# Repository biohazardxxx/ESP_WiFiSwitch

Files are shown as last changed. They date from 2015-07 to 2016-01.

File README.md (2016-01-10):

# ESP WiFiSwitch
## General info
This sketch is for a WiFi enabled wall light switch with focus to reliable pushbutton switch.
In the beginning or (if no WiFi connection) it is running a web server to configure WiFI (and MQTT if desired). 
Each second start up switch will load into OTA mode. By this you can upload a new firmware (compiled *.bin file) via web browser. The OTA mode will end after set timeout and restart into desired mode.
The operation mode can be web server or MQTT to change the state of the light.
The push button have to switch to ground.
## Button functions
* Normal press less than 1 sec but more than 50ms-> Switch light.
* Restart press: 3 sec -> Restart the module.
* Reset press: 20 sec -> Clear the settings in EEPROM

## URL adresses
* While a WiFi config is not set or can't connect:
   * http://server_ip
   *-> Gives a WiFi config page 
  
* While a WiFi config is set and in Web control mode (iotMode==0):
 * http://server_ip/gpio
  * Will display the GIPIO state and a switch form for it
  
 * http://server_ip/gpio?state=0
  * Will change the GPIO directly and display the above aswell
  
 * http://server_ip/cleareeprom 
  * Will reset the WiFi setting and rest to configure mode as AP
  * 
* While in OTA mode each second start:
   * http://server_ip
   *-> Gives a WiFi config page 
  
<b>server_ip</b> is the IP address of the ESP8266 module, will be printed to Serial when the module is connected.

## Hardware setup
Your WiFi switch should be connected like this

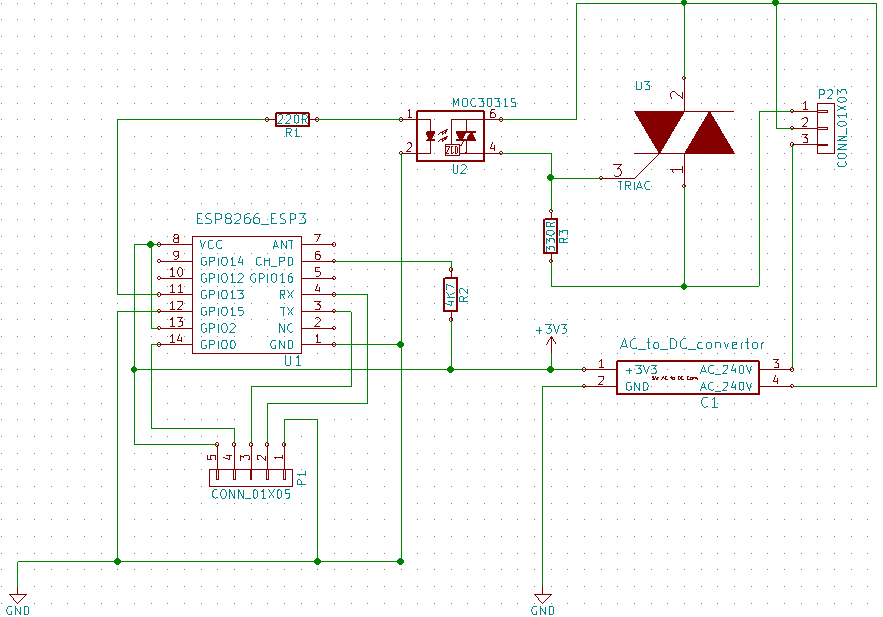
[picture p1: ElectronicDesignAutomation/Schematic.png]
Schematic


You can reorder the working PCB here: https://oshpark.com/shared_projects/xoEZ3PnV or get it from any where else from the KiCad design files "ElectronicDesignAutomation" folder.

## Parts list
* ESP8266-03 module
* AC to DC Power Module Supply Isolation Input: AC90-240V Output: 3.3V 500mA like this * http://www.ebay.com/itm/271636529720?_trksid=p2060353.m2749.l2649&ssPageName=STRK%3AMEBIDX%3AIT
* Resistor 220 Ohm SMD 1206        1x
* Resistor 330 Ohm SMD 1206        1x
* Resistor 4k7 SMD 1206   1x
* Optocuppler MOC3040  SMD      1x
* Tryac BT136D     1x

## Usage
<b>For default usage you can use the pre build firmware and flash it with NodeMcu flasher.</b>

After fresh flash please restart the module manualy (power Off & On) otherwise software restart will not work and sometimes WiFi connect does not work.

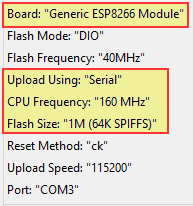
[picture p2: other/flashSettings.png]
fLashSetting
When manually compile and flash with Arduino IDE please make sure to have this flash settings: 

Open the modules page after entering config mode (Press button >20secs if you want to enter again) via http://server_ip there you can setup to be MQTT controled or Web controled.

## Credits
For several snippets used the credit goes to:
 - https://github.com/esp8266
 - https://github.com/chriscook8/esp-arduino-apboot
 - https://github.com/knolleary/pubsubclient
 - https://github.com/vicatcu/pubsubclient <- Currently this needs to be used instead of the origin
 - https://gist.github.com/igrr/7f7e7973366fc01d6393
 - http://www.esp8266.com/viewforum.php?f=25
 - http://www.esp8266.com/viewtopic.php?f=29&t=2745
 - And the whole Arduino and ESP8266 comunity

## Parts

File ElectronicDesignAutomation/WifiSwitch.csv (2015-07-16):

Reference | Value | Footprint | Datasheet
U1 | ESP8266_ESP3 | WifiSwitch:ESP8266-ESP-03
U2 | MOC3031S | WifiSwitch:DIP-6_SMD
C1 | AC_to_DC_convertor | WifiSwitch:AC_DC_Conv
R2 | 10K | Resistors_SMD:R_1206_HandSoldering
R3 | 330R | Resistors_SMD:R_1206_HandSoldering
P1 | CONN_01X05 | Pin_Headers:Pin_Header_Angled_1x05
P2 | CONN_01X03 | WifiSwitch:WirePad_3x-5mmDrill
U3 | TRIAC | Transistors_TO-220:TO-220_Neutral123_Horizontal_LargePads
R1 | 220R | Resistors_SMD:R_1206_HandSoldering

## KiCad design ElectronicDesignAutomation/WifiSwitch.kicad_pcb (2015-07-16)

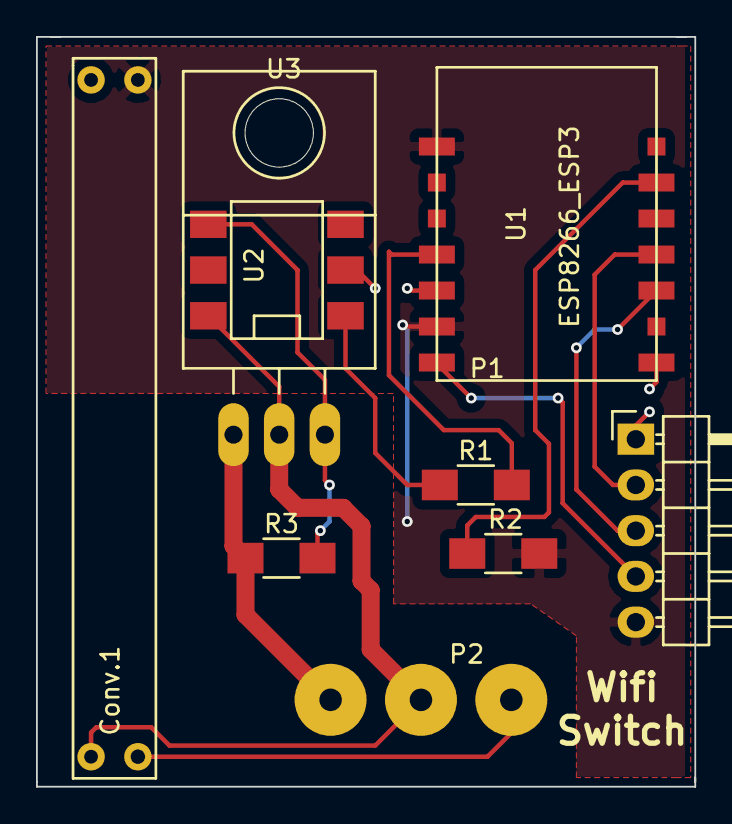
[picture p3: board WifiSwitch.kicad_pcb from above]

Board: 2 copper layers, 36.6 x 41.7 mm, 9 parts (0 on the bottom side), 12 nets.

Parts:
Conv.1: AC to DC convertor 3V3; AC_DC_Conv
P1: CONN_01X05; Pin_Header_Angled_1x05
P2: CONN_01X03; WirePad_3x-5mmDrill
R1: 220R; R_1206_HandSoldering
R2: 4K7; R_1206_HandSoldering
R3: 330R; R_1206_HandSoldering
U1: ESP8266_ESP3; ESP8266-ESP-03
U2: MOC3031S; DIP-6_SMD
U3: TRIAC; TO-220_Neutral123_Horizontal_LargePads

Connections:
+3V3: Conv.1.1, P1.5, R2.2, U1.8, U1.13
GND: Conv.1.2, P1.1, U1.1, U1.12, U2.2
unnamed: Conv.1.3, P2.3
unnamed: Conv.1.4, P2.2, U2.6, U3.2
unnamed: P1.2, U1.4
unnamed: P1.3, U1.3
unnamed: P1.4, U1.14
unnamed: P2.1, R3.2, U3.1
unnamed: R1.1, U2.1
unnamed: R1.2, U1.11
unnamed: R2.1, U1.6
unnamed: R3.1, U2.4, U3.3

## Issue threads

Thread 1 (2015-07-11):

Disconnection after sending or receiving messages...

Rigyu, 2015-07-11:
Have been testing your awesome project but have found some bug...

The client connects successfully but after some message it drops the connection.

This is a sample output, have tested with 3 different servers. ¿Any help?

 .....
WiFi connected
Connecting to MQTT server test.mosquitto.org as WiFiSwitch-18:fe:34:9f:9b:30
Connected to MQTT broker
Subsribed to topic.
MQTT message arrived:  topic: test message: 1
Light is 0
Switching light to high
MQTT message arrived:  topic: test message: 1
Light is 1
Switching light to high
Connecting to MQTT server test.mosquitto.org as WiFiSwitch-18:fe:34:9f:9b:30-18:fe:34:9f:9b:30
MQTT connect failed!
Connecting to MQTT server test.mosquitto.org as WiFiSwitch-18:fe:34:9f:9b:30-18:fe:34:9f:9b:30-18:fe:34:9f:9b:30
MQTT connect failed!
Connecting to MQTT server test.mosquitto.org as WiFiSwitch-18:fe:34:9f:9b:30-18:fe:34:9f:9b:30-18:fe:34:9f:9b:30-18:fe:34:9f:9b:30
MQTT connect failed!
Connecting to MQTT server test.mosquitto.org as WiFiSwitch-18:fe:34:9f:9b:30-18:fe:34:9f:9b:30-18:fe:34:9f:9b:30-18:fe:34:9f:9b:30-18:fe:34:9f:9b:30

Also tested in a private sever with mosquitto 1.4.2.

biohazardxxx, 2015-07-11:
Hi,
I'm using mosquito 1.3.1 on debian. Can you try with that Version? I'm not
sure yet what versions are supported by pubsubclient.
Br
Bio
Am 11.07.2015 3:57 vorm. schrieb "Rigyu" <notifications@github.com>:

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

Rigyu, 2015-07-11:
Used mosquito 1.3.1 debian install... same result. It connects 5 ~ 10 seconds, then it goes forever in "Connecting to [...]..."

Rigyu, 2015-07-11:
SOLVED. Was my router fault. I have a TP-Link "TL-WR741ND" with bgn mixed mode selected, changed to use only b and now the connection it's ok. Thank you for your time.

biohazardxxx, 2015-07-12:
Glad you solved it!

Closed 2015-07-12.

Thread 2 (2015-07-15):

mqtt works perfectly but http code hangs after a few minutes

rajbadri, 2015-07-15:
hi
i tested a relay connected to the esp8266 in mqtt mode and the setup ran perfectly for days but when i put the esp in http mode it stops responding after a few minutes.

biohazardxxx, 2015-07-17:
Hi,
I could not recreate your described issue.
(18:58:52.25) Startup
(18:58:52.40) Connecting to WiFi ABCD
(18:58:52.48) Wifi test...
(18:58:53.49) .......
(18:58:56.50) WiFi connected
(18:58:56.50) mDNS responder started
(18:58:56.50) 192.168.0.144
(18:58:56.50) Web server started
(18:59:30.27) Light switched via web request to  1
(18:59:33.69) Light switched via web request to  0
(19:03:07.47) Sending 200
(19:07:04.14) Light switched via web request to  1
(19:07:08.30) Light switched via web request to  0

I've just added more logging to the sketch for this issue. Do you get anything on serial? Can you check your DHCP leas time?

biohazardxxx, 2015-08-04:
I assume you lost the interest or could fix your problem meanwhile so I'm closing this issue.

Closed 2015-08-04.

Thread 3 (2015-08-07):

getting compile error message

rajbadri, 2015-08-07:
hi
i am getting this error message when i try to compile your sketch

Arduino: 1.6.5 (Mac OS X), Board: "Generic ESP8266 Module, Serial, 80 MHz, 40MHz, DIO, 115200, 4M (3M SPIFFS)"

In file included from sketch_aug07b.ino:31:0:
/Users/rajbadri/Documents/Arduino/libraries/PubSubClient/PubSubClient.h:80:46: error: section attribute not allowed for '<anonymous>'
    boolean publish_P(char *, uint8_t PROGMEM *, unsigned int, boolean);
                                              ^
Error compiling.

biohazardxxx, 2015-08-10:
Hi,

have you made sure to use the right pubSubClient version? https://github.com/vicatcu/pubsubclient
Because I have at line 80 in PubSubClient.h:   boolean subscribe(char *);

rajbadri, 2015-08-11:
i downloaded the pubsubclient from your link but getting the same error.
i deleted all references of PROGMEM from the library and now the sketch is compiling and running ok.
but is it ok to delete PROGMEM will it affect the working of esp8266

Thanks

rajbadri, 2015-08-11:
another question : can i give the esp a fixed ip address

Thanks again

biohazardxxx, 2015-08-11:
The simple way is to assign it within your DHCP settings at your router
config. But within the sketch you can achieve it with:
WiFi.begin(<ssid>,<pass>);
IPAddress ip(192,168,1,124);
IPAddress gateway(192,168,1,1);
IPAddress subnet(255,255,255,0);
WiFi.config(ip, gateway, subnet);

but that would be static. Adding this as option to the webconfig would need
some more coding. I'll add it to the roadmap.

2015-08-11 5:58 GMT+02:00 Raj Badri <notifications@github.com>:

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

rajbadri, 2015-08-11:
Thanks

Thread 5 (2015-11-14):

Fritzing picture

rajbadri, 2015-11-14:
hi
i have ordered pcb of your design from osh-park. but being a novice don't get the layout of button correctly. if you can post a fritzing picture of your design it will be of great help. Also can i replace the Triac BT136D with BT136

thanks for your help

Raj

rajbadri, 2015-11-14:
solved it and now works like a charm

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

biohazardxxx, 2015-11-15:
Hi, sorry for late reply! Happy you could work it out. Would it be ok with you if I place the fritzing picture on the main readme of the repository? It might also help others.

rajbadri, 2015-11-16:
yes please do so
and can you please give me link for a/c fuse to use with this switch

Thanks

biohazardxxx, 2015-11-16:
thank you. No I can't since in europe we have the whole rome power line on one fuse. Some have per lights but not for only one light. However this switch itself has a current below 1000mA. Then it depends on your light.

Closed 2015-11-14.

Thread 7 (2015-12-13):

Getting error while compiling

rajbadri, 2015-12-13:
getting this error while compiling

Arduino: 1.6.5 (Mac OS X), Board: "Generic ESP8266 Module, Serial, 80 MHz, 40MHz, DIO, 115200, 4M (3M SPIFFS)"

Using library ESP8266WiFi in folder: /Users/rajbadri/Library/Arduino15/packages/esp8266/hardware/esp8266/1.6.5-947-g39819f0/libraries/ESP8266WiFi
Using library ESP8266mDNS in folder: /Users/rajbadri/Library/Arduino15/packages/esp8266/hardware/esp8266/1.6.5-947-g39819f0/libraries/ESP8266mDNS (legacy)
Using library ESP8266WebServer in folder: /Users/rajbadri/Library/Arduino15/packages/esp8266/hardware/esp8266/1.6.5-947-g39819f0/libraries/ESP8266WebServer
Using library Ticker in folder: /Users/rajbadri/Library/Arduino15/packages/esp8266/hardware/esp8266/1.6.5-947-g39819f0/libraries/Ticker
Using library PubSubClient in folder: /Users/rajbadri/Documents/Arduino/libraries/pubsubclient-2.4
Using library ArduinoJson in folder: /Users/rajbadri/Documents/Arduino/libraries/ArduinoJson

/Users/rajbadri/Library/Arduino15/packages/esp8266/tools/xtensa-lx106-elf-gcc/1.20.0-26-gb404fb9/bin/xtensa-lx106-elf-g++ -D__ets__ -DICACHE_FLASH -U__STRICT_ANSI__ -I/Users/rajbadri/Library/Arduino15/packages/esp8266/hardware/esp8266/1.6.5-947-g39819f0/tools/sdk//include -c -Os -g -mlongcalls -mtext-section-literals -fno-exceptions -fno-rtti -falign-functions=4 -std=c++11 -MMD -DF_CPU=80000000L -DARDUINO=10605 -DARDUINO_ESP8266_ESP01 -DARDUINO_ARCH_ESP8266 -DESP8266 -I/Users/rajbadri/Library/Arduino15/packages/esp8266/hardware/esp8266/1.6.5-947-g39819f0/cores/esp8266 -I/Users/rajbadri/Library/Arduino15/packages/esp8266/hardware/esp8266/1.6.5-947-g39819f0/variants/generic -I/Users/rajbadri/Library/Arduino15/packages/esp8266/hardware/esp8266/1.6.5-947-g39819f0/libraries/ESP8266WiFi/src -I/Users/rajbadri/Library/Arduino15/packages/esp8266/hardware/esp8266/1.6.5-947-g39819f0/libraries/ESP8266mDNS -I/Users/rajbadri/Library/Arduino15/packages/esp8266/hardware/esp8266/1.6.5-947-g39819f0/libraries/ESP8266WebServer/src -I/Users/rajbadri/Library/Arduino15/packages/esp8266/hardware/esp8266/1.6.5-947-g39819f0/libraries/Ticker -I/Users/rajbadri/Documents/Arduino/libraries/pubsubclient-2.4/src -I/Users/rajbadri/Documents/Arduino/libraries/ArduinoJson/src /var/folders/hg/jblrvjks6tl65wsrsc7fs9c00000gn/T/build399527398758220727.tmp/ESP_WiFiSwitch.cpp -o /var/folders/hg/jblrvjks6tl65wsrsc7fs9c00000gn/T/build399527398758220727.tmp/ESP_WiFiSwitch.cpp.o
serverFunctions.ino: In function 'void launchWeb(int)':
serverFunctions.ino:136:8: error: no matching function for call to 'ESP8266WebServer::on(const char [8], HTTPMethod, launchWeb(int)::__lambda1, launchWeb(int)::__lambda2)'
serverFunctions.ino:136:8: note: candidates are:
In file included from ESP_WiFiSwitch.ino:45:0:
/Users/rajbadri/Library/Arduino15/packages/esp8266/hardware/esp8266/1.6.5-947-g39819f0/libraries/ESP8266WebServer/src/ESP8266WebServer.h:60:8: note: void ESP8266WebServer::on(const char*, ESP8266WebServer::THandlerFunction)
   void on(const char* uri, THandlerFunction handler);
        ^
/Users/rajbadri/Library/Arduino15/packages/esp8266/hardware/esp8266/1.6.5-947-g39819f0/libraries/ESP8266WebServer/src/ESP8266WebServer.h:60:8: note:   candidate expects 2 arguments, 4 provided
/Users/rajbadri/Library/Arduino15/packages/esp8266/hardware/esp8266/1.6.5-947-g39819f0/libraries/ESP8266WebServer/src/ESP8266WebServer.h:61:8: note: void ESP8266WebServer::on(const char*, HTTPMethod, ESP8266WebServer::THandlerFunction)
   void on(const char* uri, HTTPMethod method, THandlerFunction fn);
        ^
/Users/rajbadri/Library/Arduino15/packages/esp8266/hardware/esp8266/1.6.5-947-g39819f0/libraries/ESP8266WebServer/src/ESP8266WebServer.h:61:8: note:   candidate expects 3 arguments, 4 provided
serverFunctions.ino:167:22: error: 'class PubSubClient' has no member named 'setBrokerDomain'
serverFunctions.ino:168:22: error: 'class PubSubClient' has no member named 'setPort'
no matching function for call to 'ESP8266WebServer::on(const char [8], HTTPMethod, launchWeb(int)::__lambda1, launchWeb(int)::__lambda2)'

Please guide
Thanks

biohazardxxx, 2015-12-13:
Hi,

please use latest staging version 2.0.0-rc2 of ESP8266 arduino package.
Also If you are using an ESP-03 please use flash settings: 1M

rajbadri, 2015-12-13:
still getting the same error after update

Arduino: 1.6.5 (Mac OS X), Board: "Generic ESP8266 Module, Serial, 80 MHz, 40MHz, DIO, 115200, 4M (3M SPIFFS)"

Using library ESP8266WiFi in folder: /Users/rajbadri/Library/Arduino15/packages/esp8266/hardware/esp8266/1.6.5-947-g39819f0/libraries/ESP8266WiFi
Using library ESP8266mDNS in folder: /Users/rajbadri/Library/Arduino15/packages/esp8266/hardware/esp8266/1.6.5-947-g39819f0/libraries/ESP8266mDNS (legacy)
Using library ESP8266WebServer in folder: /Users/rajbadri/Library/Arduino15/packages/esp8266/hardware/esp8266/1.6.5-947-g39819f0/libraries/ESP8266WebServer
Using library Ticker in folder: /Users/rajbadri/Library/Arduino15/packages/esp8266/hardware/esp8266/1.6.5-947-g39819f0/libraries/Ticker
Using library PubSubClient in folder: /Users/rajbadri/Documents/Arduino/libraries/pubsubclient
Using library ArduinoJson in folder: /Users/rajbadri/Documents/Arduino/libraries/ArduinoJson

/Users/rajbadri/Library/Arduino15/packages/esp8266/tools/xtensa-lx106-elf-gcc/1.20.0-26-gb404fb9/bin/xtensa-lx106-elf-g++ -D__ets__ -DICACHE_FLASH -U__STRICT_ANSI__ -I/Users/rajbadri/Library/Arduino15/packages/esp8266/hardware/esp8266/1.6.5-947-g39819f0/tools/sdk//include -c -Os -g -mlongcalls -mtext-section-literals -fno-exceptions -fno-rtti -falign-functions=4 -std=c++11 -MMD -DF_CPU=80000000L -DARDUINO=10605 -DARDUINO_ESP8266_ESP01 -DARDUINO_ARCH_ESP8266 -DESP8266 -I/Users/rajbadri/Library/Arduino15/packages/esp8266/hardware/esp8266/1.6.5-947-g39819f0/cores/esp8266 -I/Users/rajbadri/Library/Arduino15/packages/esp8266/hardware/esp8266/1.6.5-947-g39819f0/variants/generic -I/Users/rajbadri/Library/Arduino15/packages/esp8266/hardware/esp8266/1.6.5-947-g39819f0/libraries/ESP8266WiFi/src -I/Users/rajbadri/Library/Arduino15/packages/esp8266/hardware/esp8266/1.6.5-947-g39819f0/libraries/ESP8266mDNS -I/Users/rajbadri/Library/Arduino15/packages/esp8266/hardware/esp8266/1.6.5-947-g39819f0/libraries/ESP8266WebServer/src -I/Users/rajbadri/Library/Arduino15/packages/esp8266/hardware/esp8266/1.6.5-947-g39819f0/libraries/Ticker -I/Users/rajbadri/Documents/Arduino/libraries/pubsubclient/src -I/Users/rajbadri/Documents/Arduino/libraries/ArduinoJson/src /var/folders/hg/jblrvjks6tl65wsrsc7fs9c00000gn/T/build1018353757235617151.tmp/ESP_WiFiSwitch.cpp -o /var/folders/hg/jblrvjks6tl65wsrsc7fs9c00000gn/T/build1018353757235617151.tmp/ESP_WiFiSwitch.cpp.o
serverFunctions.ino: In function 'void launchWeb(int)':
serverFunctions.ino:136:8: error: no matching function for call to 'ESP8266WebServer::on(const char [8], HTTPMethod, launchWeb(int)::__lambda1, launchWeb(int)::__lambda2)'
serverFunctions.ino:136:8: note: candidates are:
In file included from ESP_WiFiSwitch.ino:45:0:
/Users/rajbadri/Library/Arduino15/packages/esp8266/hardware/esp8266/1.6.5-947-g39819f0/libraries/ESP8266WebServer/src/ESP8266WebServer.h:60:8: note: void ESP8266WebServer::on(const char*, ESP8266WebServer::THandlerFunction)
   void on(const char* uri, THandlerFunction handler);
        ^
/Users/rajbadri/Library/Arduino15/packages/esp8266/hardware/esp8266/1.6.5-947-g39819f0/libraries/ESP8266WebServer/src/ESP8266WebServer.h:60:8: note:   candidate expects 2 arguments, 4 provided
/Users/rajbadri/Library/Arduino15/packages/esp8266/hardware/esp8266/1.6.5-947-g39819f0/libraries/ESP8266WebServer/src/ESP8266WebServer.h:61:8: note: void ESP8266WebServer::on(const char*, HTTPMethod, ESP8266WebServer::THandlerFunction)
   void on(const char* uri, HTTPMethod method, THandlerFunction fn);
        ^
/Users/rajbadri/Library/Arduino15/packages/esp8266/hardware/esp8266/1.6.5-947-g39819

f0/libraries/ESP8266WebServer/src/ESP8266WebServer.h:61:8: note:   candidate expects 3 arguments, 4 provided
serverFunctions.ino:167:22: error: 'class PubSubClient' has no member named 'setBrokerDomain'
serverFunctions.ino:168:22: error: 'class PubSubClient' has no member named 'setPort'
no matching function for call to 'ESP8266WebServer::on(const char [8], HTTPMethod, launchWeb(int)::__lambda1, launchWeb(int)::__lambda2)'

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

biohazardxxx, 2015-12-14:
Did you restart arduino IDE after update?

biohazardxxx, 2016-02-19:
I'll close this now. Let me know if you still need help.

Closed 2016-02-19.

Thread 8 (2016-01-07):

getting error when compiling please help

rajbadri, 2016-01-07:
all this while i am using the older version of your sketch. and it works perfectly

trying to compile the new version but it gives error

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

the detailed error message is

Arduino: 1.6.5 (Mac OS X), Board: "NodeMCU 1.0 (ESP-12E Module), 80 MHz, Serial, 115200, 4M (3M SPIFFS)"

Build options changed, rebuilding all
Using library ESP8266WiFi in folder: /Users/rajbadri/Library/Arduino15/packages/esp8266/hardware/esp8266/2.1.0-rc1/libraries/ESP8266WiFi
Using library ESP8266mDNS in folder: /Users/rajbadri/Library/Arduino15/packages/esp8266/hardware/esp8266/2.1.0-rc1/libraries/ESP8266mDNS (legacy)
Using library ESP8266WebServer in folder: /Users/rajbadri/Library/Arduino15/packages/esp8266/hardware/esp8266/2.1.0-rc1/libraries/ESP8266WebServer
Using library Ticker in folder: /Users/rajbadri/Library/Arduino15/packages/esp8266/hardware/esp8266/2.1.0-rc1/libraries/Ticker
Using library PubSubClient in folder: /Users/rajbadri/Documents/Arduino/libraries/PubSubClient (legacy)
Using library ArduinoJson in folder: /Users/rajbadri/Documents/Arduino/libraries/ArduinoJson (legacy)

/Users/rajbadri/Library/Arduino15/packages/esp8266/tools/xtensa-lx106-elf-gcc/1.20.0-26-gb404fb9-2/bin/xtensa-lx106-elf-g++ -D__ets__ -DICACHE_FLASH -U__STRICT_ANSI__ -I/Users/rajbadri/Library/Arduino15/packages/esp8266/hardware/esp8266/2.1.0-rc1/tools/sdk/include -c -Os -g -mlongcalls -mtext-section-literals -fno-exceptions -fno-rtti -falign-functions=4 -std=c++11 -MMD -ffunction-sections -fdata-sections -DF_CPU=80000000L -DARDUINO=10605 -DARDUINO_ESP8266_ESP12 -DARDUINO_ARCH_ESP8266 -DESP8266 -I/Users/rajbadri/Library/Arduino15/packages/esp8266/hardware/esp8266/2.1.0-rc1/cores/esp8266 -I/Users/rajbadri/Library/Arduino15/packages/esp8266/hardware/esp8266/2.1.0-rc1/variants/nodemcu -I/Users/rajbadri/Library/Arduino15/packages/esp8266/hardware/esp8266/2.1.0-rc1/libraries/ESP8266WiFi/src -I/Users/rajbadri/Library/Arduino15/packages/esp8266/hardware/esp8266/2.1.0-rc1/libraries/ESP8266mDNS -I/Users/rajbadri/Library/Arduino15/packages/esp8266/hardware/esp8266/2.1.0-rc1/libraries/ESP8266WebServer/src -I/Users/rajbadri/Library/Arduino15/packages/esp8266/hardware/esp8266/2.1.0-rc1/libraries/Ticker -I/Users/rajbadri/Documents/Arduino/libraries/PubSubClient -I/Users/rajbadri/Documents/Arduino/libraries/ArduinoJson /var/folders/hg/jblrvjks6tl65wsrsc7fs9c00000gn/T/build989273569338910562.tmp/ESP_WiFiSwitch.cpp -o /var/folders/hg/jblrvjks6tl65wsrsc7fs9c00000gn/T/build989273569338910562.tmp/ESP_WiFiSwitch.cpp.o
ConfigFunctions.ino: In function 'bool loadConfig()':
ConfigFunctions.ino:31:29: error: conversion from 'ArduinoJson::JsonVariant' to non-scalar type 'String' requested
ConfigFunctions.ino:32:31: error: conversion from 'ArduinoJson::JsonVariant' to non-scalar type 'String' requested
ConfigFunctions.ino:34:37: error: conversion from 'ArduinoJson::JsonVariant' to non-scalar type 'String' requested
ConfigFunctions.ino:35:37: error: conversion from 'ArduinoJson::JsonVariant' to non-scalar type 'String' requested
ConfigFunctions.ino:36:41: error: conversion from 'ArduinoJson::JsonVariant' to non-scalar type 'String' requested
conversion from 'ArduinoJson::JsonVariant' to non-scalar type 'String' requested

i am using arduino ide 1.6.5 and boards version 2.1.0-rc1

Please guide

Thanks

biohazardxxx, 2016-01-07:
Hi,
Please remobe the esp package via boards manager in the IDE and then install latest staging again. This helped a few times.

Closed 2016-02-19.

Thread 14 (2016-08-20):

Trying to find AC-dc

raymatos, 2016-08-20:
Can you point me in the right direction, I can't find the AC-dc that goes with your pcb design

Feryy, 2017-07-27:
That's what interests me. I use this:

Http://www.ebay.com/itm/HLK-PM03-AC-DC-220V-to-3-3V-Step-Down-Buck-Isolated-Power-Supply-Module-/311759562967?hash=item48965168d7:g : XsQAAOSwnHZYUHS7

But it requires a filter capacitor. Yours is very small.

biohazardxxx, 2017-07-27:
Search for bug step down 3.3v like
http://m.ebay.com/itm/AC-DC-Power-Supply-Buck-Converter-Step-Down-Module-110V-220V-TO-3-3V-700mA-3w-/171923719338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

Am 27.07.2017 10:19 schrieb "Feryy" <notifications@github.com>:

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

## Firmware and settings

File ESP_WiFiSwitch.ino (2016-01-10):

/*
 *  This sketch is running a web server for configuring WiFI if can't connect or for controlling of one GPIO to switch a light/LED
 *  Also it supports to change the state of the light via MQTT message and gives back the state after change.
 *  The push button has to switch to ground. It has following functions: Normal press less than 1 sec but more than 50ms-> Switch light. Restart press: 3 sec -> Restart the module. Reset press: 20 sec -> Clear the settings in EEPROM
 *  While a WiFi config is not set or can't connect:
 *    http://server_ip will give a config page with 
 *  While a WiFi config is set:
 *    http://server_ip/gpio -> Will display the GIPIO state and a switch form for it
 *    http://server_ip/gpio?state=0 -> Will change the GPIO directly and display the above aswell
 *    http://server_ip/cleareeprom -> Will reset the WiFi setting and rest to configure mode as AP
 *  server_ip is the IP address of the ESP8266 module, will be 
 *  printed to Serial when the module is connected. (most likly it will be 192.168.4.1)
 * To force AP config mode, press button 20 Secs!
 *  For several snippets used, the credit goes to:
 *  - https://github.com/esp8266
 *  - https://github.com/chriscook8/esp-arduino-apboot
 *  - https://github.com/knolleary/pubsubclient
 *  - https://github.com/vicatcu/pubsubclient <- Currently this needs to be used instead of the origin
 *  - https://gist.github.com/igrr/7f7e7973366fc01d6393
 *  - http://www.esp8266.com/viewforum.php?f=25
 *  - http://www.esp8266.com/viewtopic.php?f=29&t=2745
 *  - And the whole Arduino and ESP8266 comunity
 */

#define DEBUG
//#define WEBOTA
//debug added for information, change this according your needs

#ifdef DEBUG
  #define Debug(x)    Serial.print(x)
  #define Debugln(x)  Serial.println(x)
  #define Debugf(...) Serial.printf(__VA_ARGS__)
  #define Debugflush  Serial.flush
#else
  #define Debug(x)    {}
  #define Debugln(x)  {}
  #define Debugf(...) {}
  #define Debugflush  {}
#endif


#include <ESP8266WiFi.h>
#include <ESP8266mDNS.h>
#include <WiFiClient.h>
#include <ESP8266WebServer.h>
//#include <EEPROM.h>
#include <Ticker.h>
#include <PubSubClient.h>
#include <ArduinoJson.h>
#include "FS.h"

extern "C" {
  #include "user_interface.h" //Needed for the reset command
}

//***** Settings declare ********************************************************************************************************* 
String hostName ="WiFiSwitch"; //The MQTT ID -> MAC adress will be added to make it kind of unique
int iotMode=0; //IOT mode: 0 = Web control, 1 = MQTT (No const since it can change during runtime)
//select GPIO's
#define OUTPIN 13 //output pin
#define INPIN 0  // input pin (push button)

#define RESTARTDELAY 3 //minimal time in sec for button press to reset
#define HUMANPRESSDELAY 50 // the delay in ms untill the press should be handled as a normal push by human. Button debounce. !!! Needs to be less than RESTARTDELAY & RESETDELAY!!!
#define RESETDELAY 20 //Minimal time in sec for button press to reset all settings and boot to config mode

//##### Object instances ##### 
MDNSResponder mdns;
ESP8266WebServer server(80);
WiFiClient wifiClient;
PubSubClient mqttClient;
Ticker btn_timer;
Ticker otaTickLoop;

//##### Flags ##### They are needed because the loop needs to continue and cant wait for long tasks!
int rstNeed=0;   // Restart needed to apply new settings
int toPub=0; // determine if state should be published.
int configToClear=0; // determine if config should be cleared.
int otaFlag=0;
boolean inApMode=0;
//##### Global vars ##### 
int webtypeGlob;
int otaCount=300; //imeout in sec for OTA mode
int current; //Current state of the button
unsigned long count = 0; //Button press time counter
String st; //WiFi Stations HTML list
String state; //State of light
char buf[40]; //For MQTT data recieve
char* host; //The DNS hostname
//To be read from Config file
String esid="";
String epass = "";
String pubTopic;
String subTopic;
String mqttServer = "";
const char* otaServerIndex = "<form method='POST' action='/update' enctype='multipart/form-data'><input type='file' name='update'><input type='submit' value='Update'></form>";

//-------------- void's -------------------------------------------------------------------------------------
void setup() {
  Serial.begin(115200);
  delay(10);
  // prepare GPIO2
  pinMode(OUTPIN, OUTPUT);
  pinMode(INPIN, INPUT_PULLUP);
  btn_timer.attach(0.05, btn_handle);
  Debugln("DEBUG: Entering loadConfig()");
  if (!SPIFFS.begin()) {
    Serial.println("Failed to mount file system");
  }
  
  uint8_t mac[6];
  WiFi.macAddress(mac);
  hostName += "-";
  hostName += macToStr(mac);
  String hostTemp=hostName;
  hostTemp.replace(":","-");
  host = (char*) hostTemp.c_str();
  loadConfig();
  //loadConfigOld();
  Debugln("DEBUG: loadConfig() passed");
  
  // Connect to WiFi network
  Debugln("DEBUG: Entering initWiFi()");
  initWiFi();
  Debugln("DEBUG: initWiFi() passed");
  Debug("iotMode:");
  Debugln(iotMode);
  Debug("webtypeGlob:");
  Debugln(webtypeGlob);
  Debug("otaFlag:");
  Debugln(otaFlag);
  Debugln("DEBUG: Starting the main loop");
}


void btn_handle()
{
  if(!digitalRead(INPIN)){
    ++count; // one count is 50ms
  } else {
    if (count > 1 && count < HUMANPRESSDELAY/5) { //push between 50 ms and 1 sec      
      Serial.print("button pressed "); 
      Serial.print(count*0.05); 
      Serial.println(" Sec."); 
    
      Serial.print("Light is ");
      Serial.println(digitalRead(OUTPIN));
      
      Serial.print("Switching light to "); 
      Serial.println(!digitalRead(OUTPIN));
      digitalWrite(OUTPIN, !digitalRead(OUTPIN)); 
      state = digitalRead(OUTPIN);
      if(iotMode==1 && mqttClient.connected()){
        toPub=1;        
        Debugln("DEBUG: toPub set to 1");
      }
    } else if (count > (RESTARTDELAY/0.05) && count <= (RESETDELAY/0.05)){ //pressed 3 secs (60*0.05s)
      Serial.print("button pressed "); 
      Serial.print(count*0.05); 
      Serial.println(" Sec. Restarting!"); 
      setOtaFlag(!otaFlag);      
      ESP.reset();
    } else if (count > (RESETDELAY/0.05)){ //pressed 20 secs
      Serial.print("button pressed "); 
      Serial.print(count*0.05); 
      Serial.println(" Sec."); 
      Serial.println(" Clear settings and resetting!");       
      configToClear=1;
      }
    count=0; //reset since we are at high
  }
}



//-------------------------------- Main loop ---------------------------
void loop() {
  //Debugln("DEBUG: loop() begin");
  if(configToClear==1){
    //Debugln("DEBUG: loop() clear config flag set!");
    clearConfig()? Serial.println("Config cleared!") : Serial.println("Config could not be cleared");
    delay(1000);
    ESP.reset();
  }
  //Debugln("DEBUG: config reset check passed");  
  if (WiFi.status() == WL_CONNECTED && otaFlag){
    if(otaCount<=1) {
      Serial.println("OTA mode time out. Reset!"); 
      setOtaFlag(0);
      ESP.reset();
      delay(100);
    }
    server.handleClient();
    delay(1);
  } else if (WiFi.status() == WL_CONNECTED || webtypeGlob == 1){
    //Debugln("DEBUG: loop() wifi connected & webServer ");
    if (iotMode==0 || webtypeGlob == 1){
      //Debugln("DEBUG: loop() Web mode requesthandling ");
      server.handleClient();
      delay(1);
    } else if (iotMode==1 && webtypeGlob != 1 && otaFlag !=1){
          //Debugln("DEBUG: loop() MQTT mode requesthandling ");
          if (!connectMQTT()){
              delay(200);          
          }                    
          if (mqttClient.connected()){            
              //Debugln("mqtt handler");
              mqtt_handler();
          } else {
              Debugln("mqtt Not connected!");
          }
    }
  } else{
    Debugln("DEBUG: loop - WiFi not connected");  
    delay(1000);
    initWiFi(); //Try to connect again
  }
    //Debugln("DEBUG: loop() end");
}

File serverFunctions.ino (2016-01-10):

void initWiFi(){
  Serial.println();
  Serial.println();
  Serial.println("Startup");
  
  // test esid 
  WiFi.disconnect();
  delay(100);
  WiFi.mode(WIFI_STA);
  Serial.print("Connecting to WiFi ");
  Serial.println(esid);
  Debugln(epass);
  WiFi.begin((char*)esid.c_str(), (char*)epass.c_str());
  if ( testWifi() == 20 ) { 
      launchWeb(0);
      return;
  }
  Serial.println("Opening AP");
  setupAP();   
}

int testWifi(void) {
  int c = 0;
  Debugln("Wifi test...");  
  while ( c < 30 ) {
    if (WiFi.status() == WL_CONNECTED) { return(20); } 
    delay(500);
    Serial.print(".");    
    c++;
  }
  Serial.println("WiFi Connect timed out!");
  return(10);
} 


void setupAP(void) {
  
  WiFi.mode(WIFI_STA);
  WiFi.disconnect();
  delay(100);
  int n = WiFi.scanNetworks();
  Serial.println("scan done");
  if (n == 0){
    Serial.println("no networks found");
    st ="<b>No networks found:</b>";
  } else {
    Serial.print(n);
    Serial.println(" Networks found");
    st = "<ul>";
    for (int i = 0; i < n; ++i)
     {
      // Print SSID and RSSI for each network found
      Serial.print(i + 1);
      Serial.print(": ");
      Serial.print(WiFi.SSID(i));
      Serial.print(" (");
      Serial.print(WiFi.RSSI(i));
      Serial.print(")");
      Serial.println((WiFi.encryptionType(i) == ENC_TYPE_NONE)?" (OPEN)":"*");
      
      // Print to web SSID and RSSI for each network found
      st += "<li>";
      st +=i + 1;
      st += ": ";
      st += WiFi.SSID(i);
      st += " (";
      st += WiFi.RSSI(i);
      st += ")";
      st += (WiFi.encryptionType(i) == ENC_TYPE_NONE)?" (OPEN)":"*";
      st += "</li>";
      delay(10);
     }
    st += "</ul>";
  }
  Serial.println(""); 
  WiFi.disconnect();
  delay(100);
  WiFi.mode(WIFI_AP);

  
  WiFi.softAP(host);
  WiFi.begin(host); // not sure if need but works
  Serial.print("Access point started with name ");
  Serial.println(host);
  inApMode=1;
  launchWeb(1);
}

void launchWeb(int webtype) {
    Serial.println("");
    Serial.println("WiFi connected");    
    //Start the web server or MQTT
    if(otaFlag==1 && !inApMode){
      Serial.println("Starting OTA mode.");    
      Serial.printf("Sketch size: %u\n", ESP.getSketchSize());
      Serial.printf("Free size: %u\n", ESP.getFreeSketchSpace());
      MDNS.begin(host);
      server.on("/", HTTP_GET, [](){
        server.sendHeader("Connection", "close");
        server.sendHeader("Access-Control-Allow-Origin", "*");
        server.send(200, "text/html", otaServerIndex);
      });
      server.on("/update", HTTP_POST, [](){
        server.sendHeader("Connection", "close");
        server.sendHeader("Access-Control-Allow-Origin", "*");
        server.send(200, "text/plain", (Update.hasError())?"FAIL":"OK");
        setOtaFlag(0); 
        ESP.restart();
      },[](){
        HTTPUpload& upload = server.upload();
        if(upload.status == UPLOAD_FILE_START){
          //Serial.setDebugOutput(true);
          WiFiUDP::stopAll();
          Serial.printf("Update: %s\n", upload.filename.c_str());
          otaCount=300;
          uint32_t maxSketchSpace = (ESP.getFreeSketchSpace() - 0x1000) & 0xFFFFF000;
          if(!Update.begin(maxSketchSpace)){//start with max available size
            Update.printError(Serial);
          }
        } else if(upload.status == UPLOAD_FILE_WRITE){
          if(Update.write(upload.buf, upload.currentSize) != upload.currentSize){
            Update.printError(Serial);
          }
        } else if(upload.status == UPLOAD_FILE_END){
          if(Update.end(true)){ //true to set the size to the current progress
            Serial.printf("Update Success: %u\nRebooting...\n", upload.totalSize);
          } else {
            Update.printError(Serial);
          }
          Serial.setDebugOutput(false);
        }
        yield();
      });
      server.begin();
      Serial.printf("Ready! Open http://%s.local in your browser\n", host);
      MDNS.addService("http", "tcp", 80);
      otaTickLoop.attach(1, otaCountown);
    } else { 
      //setOtaFlag(1); 
      if (webtype==1 || iotMode==0){ //in config mode or WebControle
          if (webtype==1) {           
            webtypeGlob == 1;
            Serial.println(WiFi.softAPIP());
            server.on("/", webHandleConfig);
            server.on("/a", webHandleConfigSave);          
          } else {
            //setup DNS since we are a client in WiFi net
            if (!MDNS.begin(host)) {
              Serial.println("Error setting up MDNS responder!");
            } else {
              Serial.println("mDNS responder started");
              MDNS.addService("http", "tcp", 80);
            }          
            Serial.println(WiFi.localIP());
            server.on("/", webHandleRoot);  
            server.on("/cleareeprom", webHandleClearRom);
            server.on("/gpio", webHandleGpio);
          }
          //server.onNotFound(webHandleRoot);
          server.begin();
          Serial.println("Web server started");   
          webtypeGlob=webtype; //Store global to use in loop()
        } else if(webtype!=1 && iotMode==1){ // in MQTT and not in config mode     
          mqttClient.setBrokerDomain((char*) mqttServer.c_str());
          mqttClient.setPort(1883);
          mqttClient.setCallback(mqtt_arrived);
          mqttClient.setClient(wifiClient);
          if (WiFi.status() == WL_CONNECTED){
            if (!connectMQTT()){
                delay(2000);
                if (!connectMQTT()){                            
                  Serial.println("Could not connect MQTT.");
                  Serial.println("Starting web server instead.");
                  iotMode=0;
                  launchWeb(0);
                  webtypeGlob=webtype;
                }
              }                    
            }
      }
    }
}

void webHandleConfig(){
  IPAddress ip = WiFi.softAPIP();
  String ipStr = String(ip[0]) + '.' + String(ip[1]) + '.' + String(ip[2]) + '.' + String(ip[3]);
  String s;
 
  s = "Configuration of " + hostName + " at ";
  s += ipStr;
  s += "<p>";
  s += st;
  s += "<form method='get' action='a'>";
  s += "<label>SSID: </label><input name='ssid' length=32><label> Pass: </label><input name='pass' type='password' length=64></br>";
  s += "The following is not ready yet!</br>";
  s += "<label>IOT mode: </label><input type='radio' name='iot' value='0'> HTTP<input type='radio' name='iot' value='1' checked> MQTT</br>";
  s += "<label>MQTT Broker IP/DNS: </label><input name='host' length=15></br>";
  s += "<label>MQTT Publish topic: </label><input name='pubtop' length=64></br>";
  s += "<label>MQTT Subscribe topic: </label><input name='subtop' length=64></br>";
  s += "<input type='submit'></form></p>";
  s += "\r\n\r\n";
  Serial.println("Sending 200");  
  server.send(200, "text/html", s); 
}
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

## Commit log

2015-04-29 Debouncing
    implemented debouncing the pushbutton with a timer
2015-06-24 Fixed bug with MDNS
    Disabled MDNS. never got it working and gave onyl troubles
    [ESP_WiFiSwitch.ino]
2015-07-06 Added Schematics
    [WifiSwitch.sch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]
2015-07-16 Updated Schematic
    Updates Schematic and added PCB design
    [WifiSwitch.csv, WifiSwitch.kicad_pcb, WifiSwitch.sch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]
2015-09-06 AP reset counter added
    Added a 600sec. reset counter when in AP settings mode. Usefull after
    power out take and wifi is not ready that fast.
    [ESP_WiFiSwitch.ino, MQTT.ino]
2016-01-10 Fixing MQTT
    Fixed MQTT
    Added possibility to cancel OTA with restart (3 seconds press)
    [ConfigFunctions.ino, ESP_WiFiSwitch.ino, mqttFunctions.ino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]
